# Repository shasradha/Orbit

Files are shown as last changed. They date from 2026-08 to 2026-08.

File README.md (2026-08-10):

<div align="center">

# Orbit ⌚⚡

**A wearable WiFi security-testing platform, disguised as a wristwatch.**

Custom ESP8266 hardware inside a repurposed SKMEI watch case, running a modified build of Spacehuhn's ESP8266 Deauther. This repository is the complete build: KiCad schematics, bill of materials, 3D enclosure model, and adapted firmware.







[Overview](#overview) • [Hardware](#hardware) • [Firmware](#firmware) • [3D Model](#3d-model) • [Gallery](#gallery) • [Legal](#legal--ethical-use)

</div>

---

## Overview

Orbit turns a raw ESP-12E/F module into a wrist-worn WiFi security testing tool. It presents a small on-device menu — **Scan**, **Select**, **Attack**, **Packet Monitor**, **Clock** — navigated with three tactile buttons, and reports live channel activity on a 128×64 OLED.

| | |
|---|---|
| **Form factor** | Modified SKMEI digital watch case |
| **MCU** | ESP-12E / ESP-12F (ESP8266) |
| **Display** | 0.96" I2C OLED (SSD1306, 128×64)
| **Input** | 3× tactile buttons (Up / Down / OK) + Flash + Reset |
| **Status LED** | WS2812B addressable RGB |
| **Power** | 3.7V single-cell LiPo |
| **Firmware base** | [Spacehuhn ESP8266 Deauther](https://github.com/SpacehuhnTech/esp8266_deauther) (MIT), re-pinned and rebranded |

This repo covers both halves of the build:

- **`hardware/`** — KiCad schematics for the main board and a standalone FT232RL-based flasher board, with PDF/SVG exports so nothing requires KiCad installed to review.
- **`firmware/`** — the Deauther source, adapted to Orbit's exact GPIO map, plus a prebuilt binary in [Releases](../../releases).

> [!WARNING]
> Orbit can interfere with wireless communications (deauthentication, scanning, packet capture). Use it only on networks you own or are explicitly authorized in writing to test. Unauthorized use may violate wireless regulations (e.g. FCC Part 15 in the US) and computer-misuse laws in most jurisdictions. See [Legal & Ethical Use](#legal--ethical-use).

---

## Hardware

### Specifications

| Component | Spec |
|---|---|
| MCU | ESP-12E / ESP-12F (ESP8266) |
| Display | 0.96" I2C OLED (SSD1306, 128×64) |
| Buttons | 3× tactile (Up / Down / OK) + Flash + Reset |
| LED | WS2812B RGB, single pixel |
| Power | 3.7V single-cell LiPo, no regulator |
| Case | Modified SKMEI digital watch |

### Pinout

| Function | GPIO |
|---|---|
| Button UP | 14 |
| Button DOWN | 12 |
| Button OK | 13 |
| OLED SCL | 5 |
| OLED SDA | 4 |
| WS2812 DIN | 2 |
| Flash button | 0 |
| Reset | RST |

### Bill of Materials

| Qty | Part |
|---|---|
| 1× | ESP-12E/F module |
| 1× | 0.96" I2C OLED (SSD1306, 128×64) |
| 1× | WS2812B RGB LED breakout |
| 5× | Tactile push buttons |
| 5× | 10kΩ resistors (boot config + pull-down) |
| 1× | 3.7V LiPo battery (400 mAh+) |
| 1× | SPST slide switch |
| 1× | FT232RL USB-TTL module (flasher board only) |
| — | SKMEI digital watch case (donor) |

### Schematics

Full KiCad source lives in [`hardware/`](./hardware). PDF and SVG exports are included alongside the `.kicad_sch` files for quick review without installing KiCad.

| Board | Purpose | Files |
|---|---|---|
| **Main board** | Orbit watch — ESP-12E, OLED, buttons, WS2812, battery | `hardware/orbit-main-circuit.kicad_sch` · [PDF](./hardware/orbit-main-circuit.pdf) · [SVG](./hardware/orbit-main-circuit.svg) |
| **Flasher board** | FT232RL USB-TTL programmer for initial flashing | `hardware/orbit-flash-circuit.kicad_sch` · [PDF](./hardware/orbit-flash-circuit.pdf) · [SVG](./hardware/orbit-flash-circuit.svg) |

> **Note:** on the flasher board, UART is crossed as expected for serial programming — FT232 TXD → ESP RXD0/GPIO3, FT232 RXD → ESP TXD0/GPIO1.

---

## Firmware

Orbit's firmware is a modified build of [spacehuhn's ESP8266 Deauther](https://github.com/SpacehuhnTech/esp8266_deauther) (MIT License), re-pinned to Orbit's GPIO map with a rebranded boot screen. See [`NOTICE.md`](./NOTICE.md) for the exact scope of modifications and attribution.

### Get the prebuilt binary

Grab `Orbit-firmware-v1.0.bin` from [**Releases**](../../releases/latest) and flash directly — no build environment required.

### Build from source

```bash
git clone https://github.com/shasradha/Orbit.git
cd Orbit/firmware/Orbit-Firmware-Source/orbit_deauther
```

1. Open `orbit_deauther.ino` in **Arduino IDE 2**.
2. Install the ESP8266 board package: *Tools → Board → Boards Manager → search "esp8266"*.
3. Select **Generic ESP8266 Module** as the target board.
4. Compile.

### Flashing

Use the included [flasher circuit](./hardware/orbit-flash-circuit.pdf) (FT232RL-based) or any USB-TTL adapter:

```bash
esptool.py -p <PORT> -b 115200 write_flash 0 Orbit-firmware-v1.0.bin
```

### Status

Compiles cleanly against Orbit's custom pin configuration. **Not yet flash-tested on physical hardware after this specific pin remap** — testing reports and issues are welcome. The underlying hardware, OLED wiring, and button layout have been verified working on this exact board (see [Gallery](#gallery)).

---

## 3D Model

A 3D reconstruction of the Orbit enclosure, built from real device photos and refined in Blender, is available for interactive preview:

**→ [Orbit — 3D Model (Tripo3D)](https://studio.tripo3d.ai/3d-model/440f1f53-c45f-4885-87b7-a15c8f742168?invite_code=AO12LG)**

This is an AI-assisted reconstruction for visual reference only — it is **not dimensionally exact**. The Blender source file is in [`hardware/3d/`](./hardware/3d) for anyone who wants to inspect or rebuild it.

<div align="center">
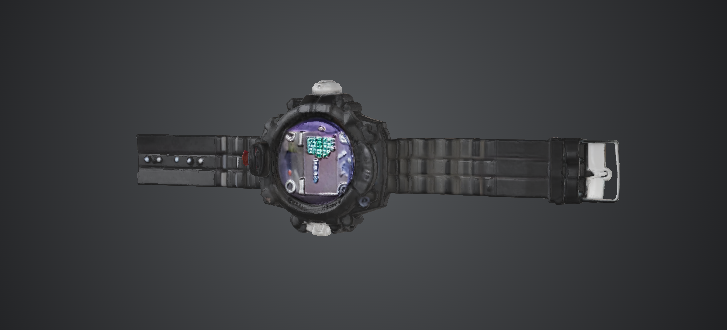
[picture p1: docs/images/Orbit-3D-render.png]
Orbit 3D render

</div>

https://github.com/user-attachments/assets/320ed174-5218-427d-8676-f516c165184d

---

## Gallery

<table>
<tr>
<td width="50%">
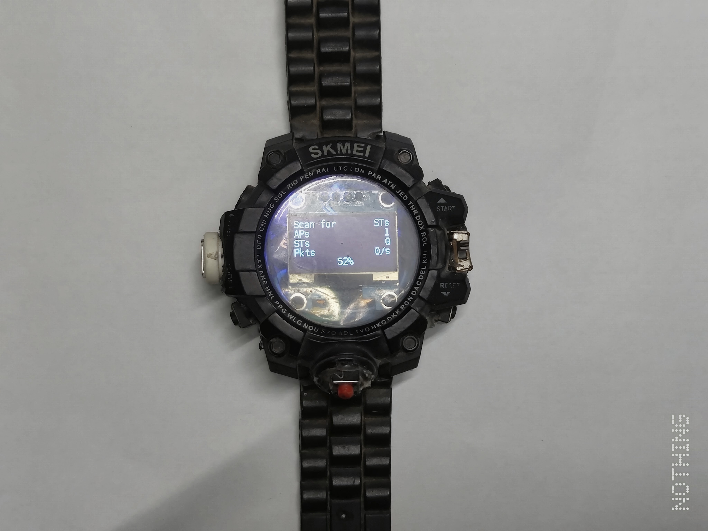
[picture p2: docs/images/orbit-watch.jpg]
Orbit assembled and worn

<p align="center"><em>Orbit, assembled and running</em></p>
</td>
<td width="50%">
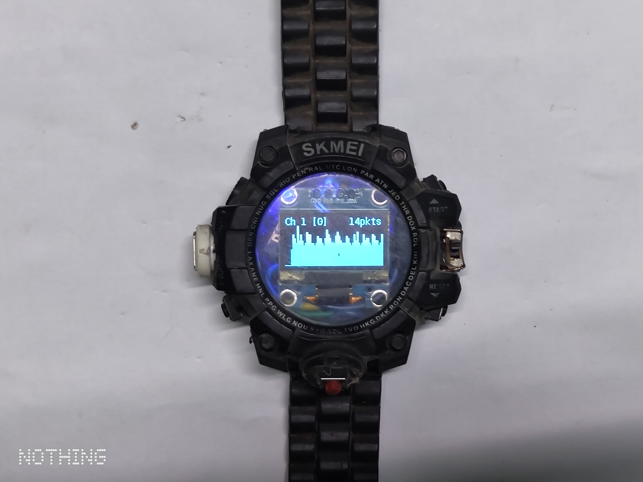
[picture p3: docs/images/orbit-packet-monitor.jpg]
Orbit packet monitor screen

<p align="center"><em>Live WiFi channel activity monitor</em></p>
</td>
</tr>
</table>

<div align="center">
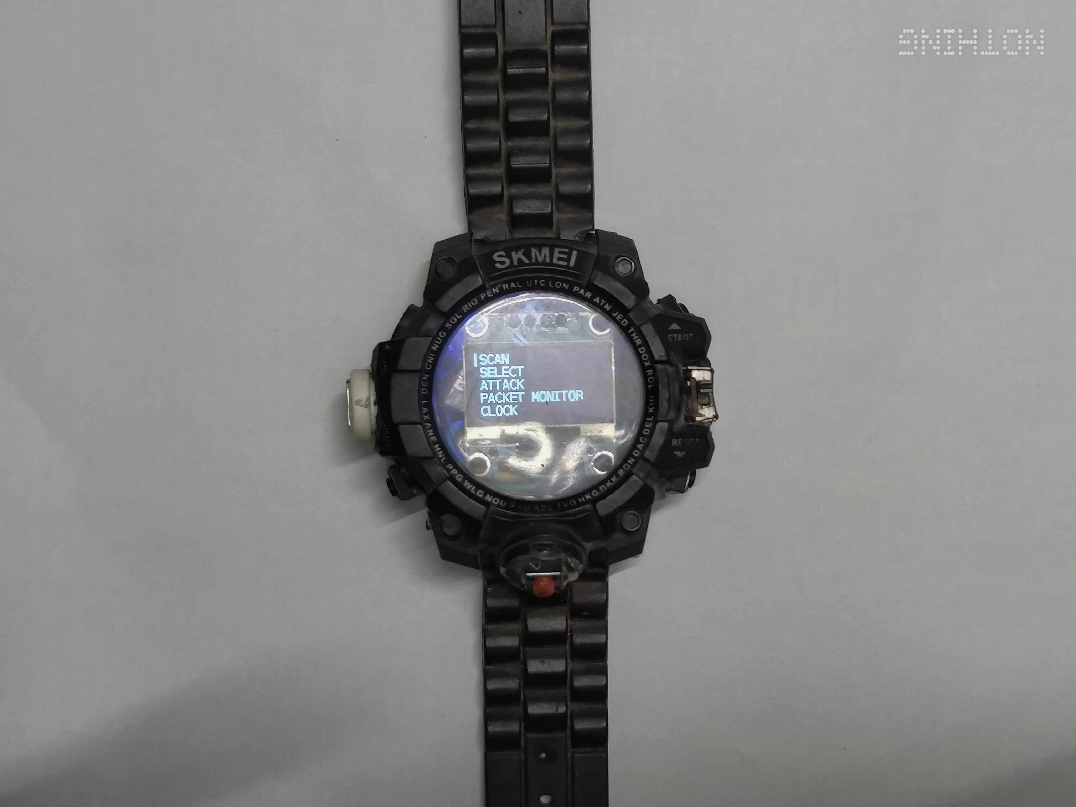
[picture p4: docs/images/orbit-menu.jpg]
Orbit main menu — Scan, Select, Attack, Packet Monitor, Clock

<p><em>On-device menu: Scan · Select · Attack · Packet Monitor · Clock</em></p>
</div>

---

## Roadmap

- [ ] Flash-test v1.0 firmware on the re-pinned hardware and confirm all menu functions
- [ ] Publish assembly / disassembly guide for the SKMEI case mod
- [ ] Add case STL/3MF export for 3D-printed enclosures
- [ ] Battery life benchmarking

---

## Contributing

Issues and pull requests are welcome — particularly flash-test reports, hardware revisions, and firmware fixes. For anything touching the deauther core itself, consider contributing upstream to [SpacehuhnTech/esp8266_deauther](https://github.com/SpacehuhnTech/esp8266_deauther) as well.

---

## Legal & Ethical Use

This project is published for **authorized security research and education only**.

- Only test networks you own, or have explicit written authorization to test.
- Deauthentication and RF interference are regulated in most jurisdictions (e.g. FCC Part 15 in the US) — unauthorized use may violate wireless and computer-misuse law.
- Per the upstream license: **do not redistribute, advertise, or sell this software (or Orbit) as a "jammer."**
- The author is not responsible for misuse of this tool.

---

## Credits

- **[Spacehuhn Technologies](https://github.com/SpacehuhnTech)** — original ESP8266 Deauther firmware (MIT License)
- **[Shasradha Karmakar](https://github.com/shasradha)** — hardware design, KiCad schematics, GPIO remap, and firmware adaptation for the Orbit platform

---

## License

MIT — see [`LICENSE`](./LICENSE) for the original firmware license and [`NOTICE.md`](./NOTICE.md) for Orbit-specific hardware and firmware modifications. Hardware design (KiCad files, BOM, 3D model) is also released under MIT.

</div>

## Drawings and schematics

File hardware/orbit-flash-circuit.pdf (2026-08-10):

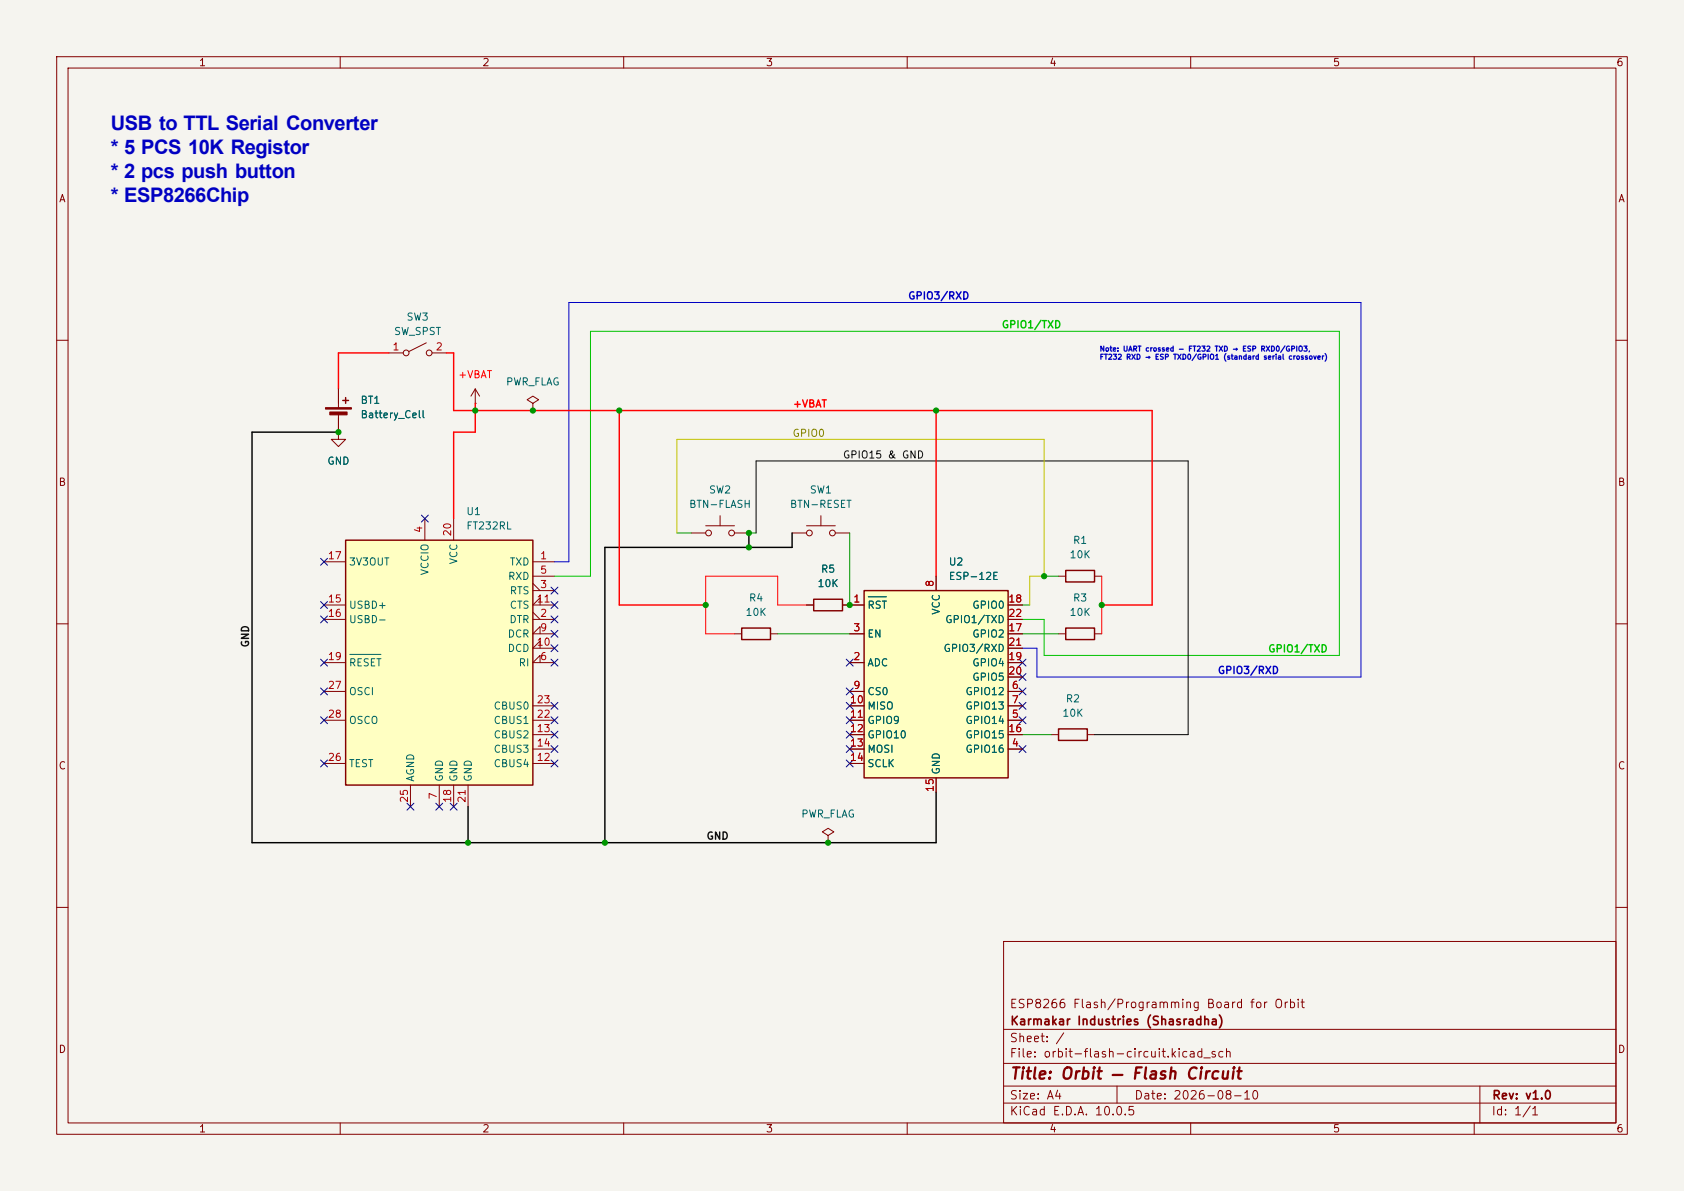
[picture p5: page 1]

GPIO15 & GND +VBAT USB to TTL Serial Converter
* 5 PCS 10K Registor
* 2 pcs push button
* ESP8266Chip

Note: UART crossed - FT232 TXD → ESP RXD0/GPIO3, FT232 RXD → ESP TXD0/GPIO1 (standard serial crossover) R5

7 DCR 9 DCD 10 CTS 11 CBUS4 12 CBUS2 13 CBUS3 14 USBD+ 15 USBD- 16

ESP8266 Flash/Programming Board for Orbit
Karmakar Industries (Shasradha)
Sheet: /
File: orbit-flash-circuit.kicad_sch
Title: Orbit — Flash Circuit

Size: A4 | Rev: v1.0
KiCad E.D.A. 10.0.5 | Id: 1/1

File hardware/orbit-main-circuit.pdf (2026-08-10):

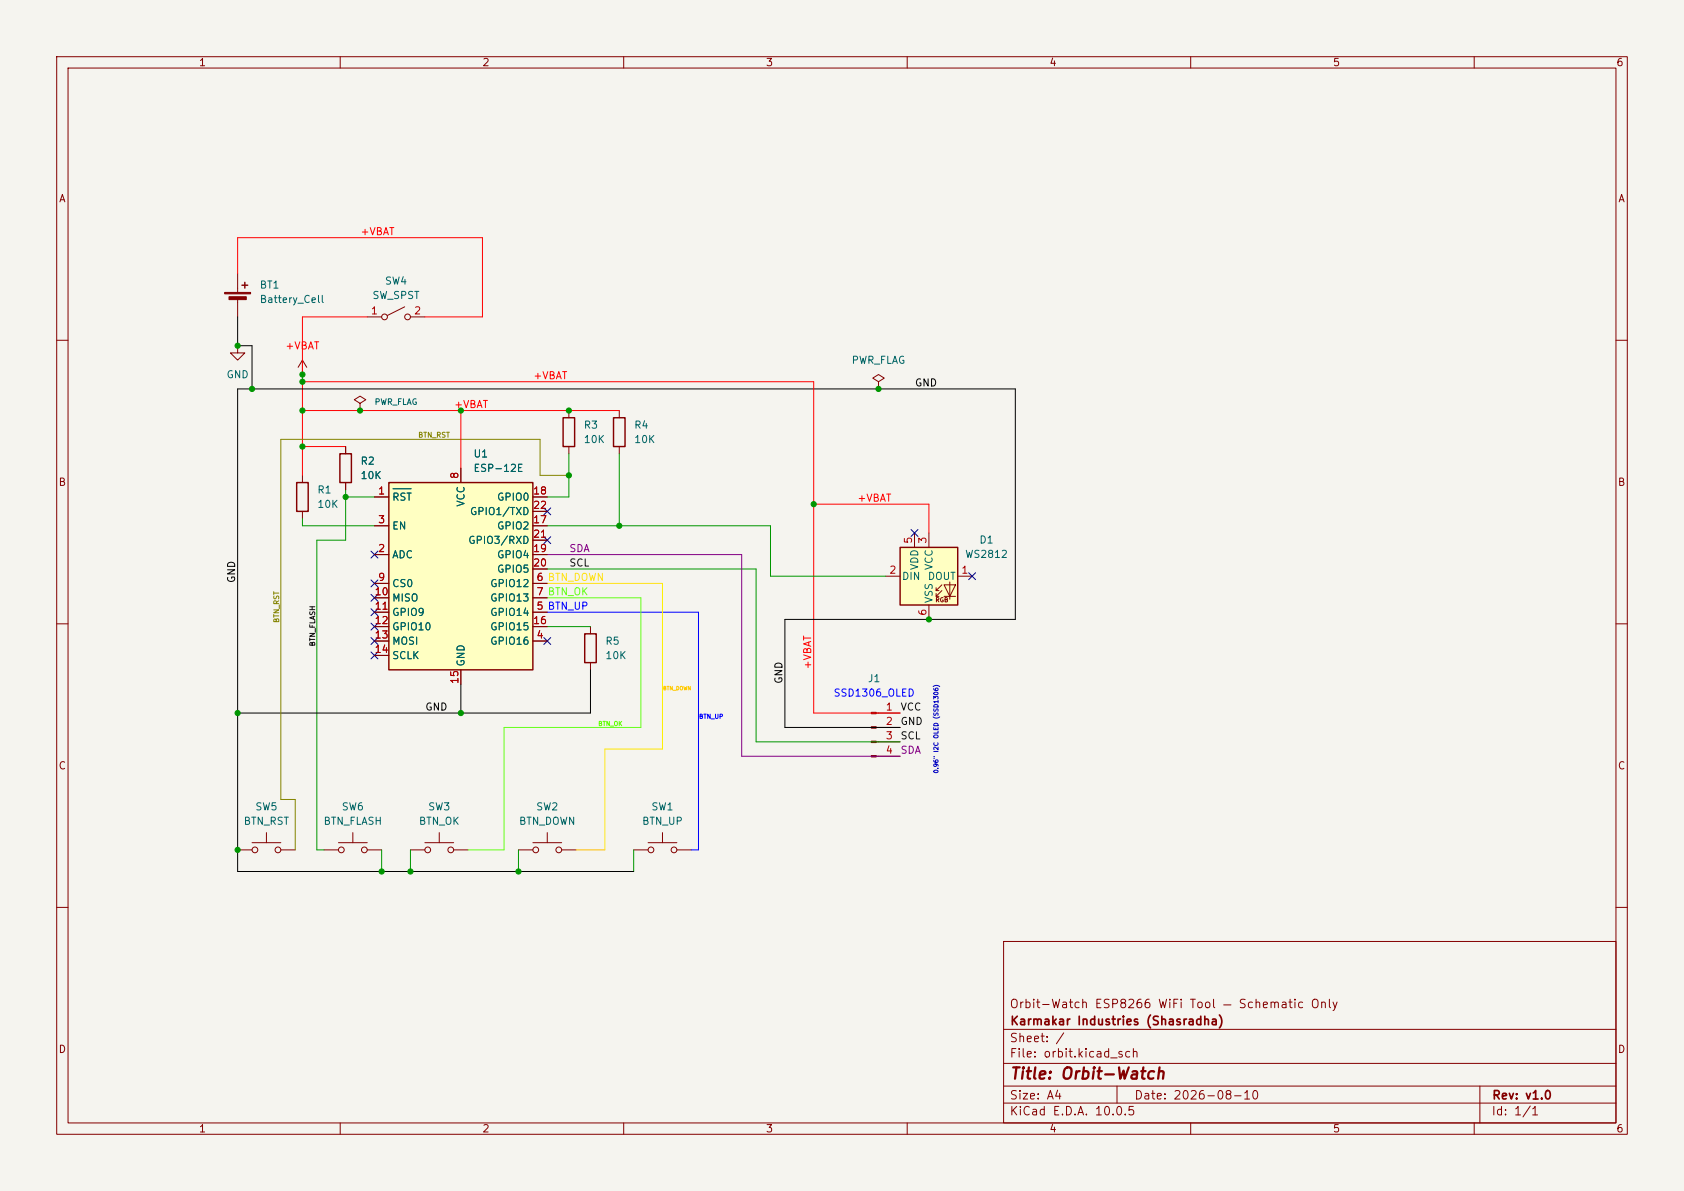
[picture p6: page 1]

Size: A4 | Rev: v1.0
KiCad E.D.A. 10.0.5 | Id: 1/1

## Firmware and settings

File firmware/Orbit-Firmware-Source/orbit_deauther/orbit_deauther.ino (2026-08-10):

/* This software is licensed under the MIT License: https://github.com/spacehuhntech/esp8266_deauther */

/* Modified for the Orbit hardware platform
   https://github.com/shasradha/Orbit
   Original firmware (c) spacehuhn, used under MIT License */

extern "C" {
    // Please follow this tutorial:
    // https://github.com/spacehuhn/esp8266_deauther/wiki/Installation#compiling-using-arduino-ide
    // And be sure to have the right board selected
  #include "user_interface.h"
}

#include "EEPROMHelper.h"

#include "src/ArduinoJson-v5.13.5/ArduinoJson.h"
#if ARDUINOJSON_VERSION_MAJOR != 5
// The software was build using ArduinoJson v5.x
// version 6 is still in beta at the time of writing
// go to tools -> manage libraries, search for ArduinoJSON and install version 5
#error Please upgrade/downgrade ArduinoJSON library to version 5!
#endif // if ARDUINOJSON_VERSION_MAJOR != 5

#include "oui.h"
#include "language.h"
#include "functions.h"
#include "settings.h"
#include "Names.h"
#include "SSIDs.h"
#include "Scan.h"
#include "Attack.h"
#include "CLI.h"
#include "DisplayUI.h"
#include "A_config.h"

#include "led.h"

// Run-Time Variables //
Names names;
SSIDs ssids;
Accesspoints accesspoints;
Stations     stations;
Scan   scan;
Attack attack;
CLI    cli;
DisplayUI displayUI;

simplebutton::Button* resetButton;

#include "wifi.h"

uint32_t autosaveTime = 0;
uint32_t currentTime  = 0;

bool booted = false;

void setup() {
    // for random generator
    randomSeed(os_random());

    // start serial
    Serial.begin(115200);
    Serial.println();

    // start SPIFFS
    prnt(SETUP_MOUNT_SPIFFS);
    // bool spiffsError = !LittleFS.begin();
    LittleFS.begin();
    prntln(/*spiffsError ? SETUP_ERROR : */ SETUP_OK);

    // Start EEPROM
    EEPROMHelper::begin(EEPROM_SIZE);

#ifdef FORMAT_SPIFFS
    prnt(SETUP_FORMAT_SPIFFS);
    LittleFS.format();
    prntln(SETUP_OK);
#endif // ifdef FORMAT_SPIFFS

#ifdef FORMAT_EEPROM
    prnt(SETUP_FORMAT_EEPROM);
    EEPROMHelper::format(EEPROM_SIZE);
    prntln(SETUP_OK);
#endif // ifdef FORMAT_EEPROM

    // Format SPIFFS when in boot-loop
    if (/*spiffsError || */ !EEPROMHelper::checkBootNum(BOOT_COUNTER_ADDR)) {
        prnt(SETUP_FORMAT_SPIFFS);
        LittleFS.format();
        prntln(SETUP_OK);

        prnt(SETUP_FORMAT_EEPROM);
        EEPROMHelper::format(EEPROM_SIZE);
        prntln(SETUP_OK);

        EEPROMHelper::resetBootNum(BOOT_COUNTER_ADDR);
    }

    // get time
    currentTime = millis();

    // load settings
    #ifndef RESET_SETTINGS
    settings::load();
    #else // ifndef RESET_SETTINGS
    settings::reset();
    settings::save();
    #endif // ifndef RESET_SETTINGS

    wifi::begin();
    wifi_set_promiscuous_rx_cb([](uint8_t* buf, uint16_t len) {
        scan.sniffer(buf, len);
    });

    // start display
    if (settings::getDisplaySettings().enabled) {
        displayUI.setup();
        displayUI.mode = DISPLAY_MODE::INTRO;
    }

    // load everything else
    names.load();
    ssids.load();
    cli.load();

    // create scan.json
    scan.setup();

    // dis/enable serial command interface
    if (settings::getCLISettings().enabled) {
        cli.enable();
    } else {
        prntln(SETUP_SERIAL_WARNING);
        Serial.flush();
        Serial.end();
    }

    // start access point/web interface
    if (settings::getWebSettings().enabled) wifi::startAP();

    // STARTED
    prntln(SETUP_STARTED);

    // version
    prntln(DEAUTHER_VERSION);

    // setup LED
    led::setup();

    // setup reset button
    resetButton = new ButtonPullup(RESET_BUTTON);
}

void loop() {
    currentTime = millis();

    led::update();   // update LED color
    wifi::update();  // manage access point
    attack.update(); // run attacks
    displayUI.update();
    cli.update();    // read and run serial input
    scan.update();   // run scan
    ssids.update();  // run random mode, if enabled

    // auto-save
    if (settings::getAutosaveSettings().enabled
        && (currentTime - autosaveTime > settings::getAutosaveSettings().time)) {
        autosaveTime = currentTime;
        names.save(false);
        ssids.save(false);
        settings::save(false);
    }

    if (!booted) {
        booted = true;
        EEPROMHelper::resetBootNum(BOOT_COUNTER_ADDR);
#ifdef HIGHLIGHT_LED
        displayUI.setupLED();
#endif // ifdef HIGHLIGHT_LED
    }

    resetButton->update();
    if (resetButton->holding(5000)) {
        led::setMode(LED_MODE::SCAN);
        DISPLAY_MODE _mode = displayUI.mode;
        displayUI.mode = DISPLAY_MODE::RESETTING;
        displayUI.update(true);

        settings::reset();
        settings::save(true);

        delay(2000);

        led::setMode(LED_MODE::IDLE);
        displayUI.mode = _mode;
    }
}

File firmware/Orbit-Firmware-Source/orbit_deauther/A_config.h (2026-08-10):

/* This software is licensed under the MIT License: https://github.com/spacehuhntech/esp8266_deauther */

/* Modified for the Orbit hardware platform
   https://github.com/shasradha/Orbit
   Original firmware (c) spacehuhn, used under MIT License */

#pragma once

#define ENABLE_DEBUG
#define DEBUG_PORT Serial
#define DEBUG_BAUD 115200

#define ORBIT
//#define DEFAULT_ESP8266

// #define NODEMCU
// #define WEMOS_D1_MINI
// #define HACKHELD_VEGA
// #define DISPLAY_EXAMPLE_I2C
// #define DISPLAY_EXAMPLE_SPI

// #define MALTRONICS
// #define DSTIKE_DEAUTHER_V1
// #define DSTIKE_DEAUTHER_V2
// #define DSTIKE_DEAUTHER_V3
// #define DSTIKE_DEAUTHER_V3_5
// #define DSTIKE_D_DUINO_B_V5_LED_RING
// #define DSTIKE_DEAUTHER_BOY
// #define DSTIKE_NODEMCU_07
// #define DSTIKE_NODEMCU_07_V2
// #define DSTIKE_DEAUTHER_OLED
// #define DSTIKE_DEAUTHER_OLED_V1_5_S
// #define DSTIKE_DEAUTHER_OLED_V1_5
// #define DSTIKE_DEAUTHER_OLED_V2
// #define DSTIKE_DEAUTHER_OLED_V2_5
// #define DSTIKE_DEAUTHER_OLED_V3
// #define DSTIKE_DEAUTHER_OLED_V3_5
// #define DSTIKE_DEAUTHER_OLED_V4
// #define DSTIKE_DEAUTHER_OLED_V5
// #define DSTIKE_DEAUTHER_OLED_V6
// #define DSTIKE_DEAUTHER_MOSTER
// #define DSTIKE_DEAUTHER_MOSTER_V2
// #define DSTIKE_DEAUTHER_MOSTER_V3
// #define DSTIKE_DEAUTHER_MOSTER_V4
// #define DSTIKE_DEAUTHER_MOSTER_V5
// #define DSTIKE_USB_DEAUTHER
// #define DSTIKE_USB_DEAUTHER_V2
// #define DSTIKE_DEAUTHER_WATCH
// #define DSTIKE_DEAUTHER_WATCH_V2
// #define DSTIKE_DEAUTHER_MINI
// #define DSTIKE_DEAUTHER_MINI_EVO

// #define LYASI_7W_E27_LAMP
// #define AVATAR_5W_E14_LAMP

// Forces formatting of SPIFFS and EEPROM ot startup
// #define FORMAT_SPIFFS
// #define FORMAT_EEPROM

// Forces a reset of all settings at startup
// #define RESET_SETTINGS

// ========== CONFIGS ========== //

// https://github.com/spacehuhntech/hackheld
#if defined(HACKHELD_VEGA)
// ===== LED ===== //
  #define USE_LED true
  #define LED_NEOPIXEL

  #define LED_NEOPIXEL_GRB
// #define LED_NEOPIXEL_RGB

  #define LED_MODE_BRIGHTNESS 10

  #define LED_NUM 1
  #define LED_NEOPIXEL_PIN 15 // D8

// ===== DISPLAY ===== //
  #define USE_DISPLAY true
  #define FLIP_DIPLAY true

  #define SH1106_I2C

  #define I2C_ADDR 0x3C
  #define I2C_SDA 4      // D2
  #define I2C_SCL 5      // D1

// ===== BUTTONS ===== //
  #define BUTTON_UP 14   // D5
  #define BUTTON_DOWN 12 // D6
  #define BUTTON_A 2     // D4
  #define BUTTON_B 0     // D3

// https://github.com/SpacehuhnTech/esp8266_deauther/wiki/Setup-Display-&-Buttons#example-setup-with-i2c-oled
#elif defined(DISPLAY_EXAMPLE_I2C)

// ===== DISPLAY ===== //
  #define SH1106_I2C
// #define SSD1306_I2C

  #define I2C_ADDR 0x3C
  #define I2C_SDA 5
  #define I2C_SCL 4

// #define FLIP_DIPLAY true

// ===== BUTTONS ===== //
  #define BUTTON_UP 14
  #define BUTTON_DOWN 12
  #define BUTTON_A 13

// ===== LED ===== //
  #define LED_NEOPIXEL_GRB
// #define LED_NEOPIXEL_RGB

  #define LED_NUM 1
  #define LED_NEOPIXEL_PIN 9
  #define LED_MODE_BRIGHTNESS 10


// https://github.com/SpacehuhnTech/esp8266_deauther/wiki/Setup-Display-&-Buttons#example-setup-with-spi-oled
#elif defined(DISPLAY_EXAMPLE_SPI)

  #define SH1106_SPI
// #define SSD1306_SPI

  #define SPI_RES 5
  #define SPI_DC 4
  #define SPI_CS 15

// #define FLIP_DIPLAY true

// ===== BUTTONS ===== //
  #define BUTTON_UP 0
  #define BUTTON_DOWN 12
  #define BUTTON_A 2

// ===== LED ===== //
  #define LED_NEOPIXEL_GRB
// #define LED_NEOPIXEL_RGB

  #define LED_NUM 1
  #define LED_NEOPIXEL_PIN 9
  #define LED_MODE_BRIGHTNESS 10

#elif defined(MALTRONICS)

// ===== Reset ====== //
  #define RESET_BUTTON 5

// ===== LED ===== //
  #define LED_DOTSTAR
  #define LED_NUM 1
  #define LED_DOTSTAR_CLK 12
  #define LED_DOTSTAR_DATA 13
  #define LED_MODE_BRIGHTNESS 255

// ===== Web ===== //
#define WEB_IP_ADDR (192, 168, 4, 2)
#define WEB_URL "deauther.tools"

#elif defined(DSTIKE_D_DUINO_B_V5_LED_RING)

// ===== LED ===== //
  #define LED_NEOPIXEL_GRB
  #define LED_NUM 12
  #define LED_NEOPIXEL_PIN 15

// ===== DISPLAY ===== //
  #define SH1106_I2C
  #define FLIP_DIPLAY true
  #define DISPLAY_TEXT "Hardware by DSTIKE"

// ===== BUTTONS ===== //
  #define BUTTON_UP 12
  #define BUTTON_DOWN 13
  #define BUTTON_A 14

#elif defined(DSTIKE_DEAUTHER_BOY)

// ===== LED ===== //
  #define LED_NEOPIXEL_GRB
  #define LED_NUM 1
  #define LED_NEOPIXEL_PIN 15

// ===== DISPLAY ===== //
  #define SH1106_I2C
  #define FLIP_DIPLAY true
  #define DISPLAY_TEXT "Hardware by DSTIKE"

// ===== BUTTONS ===== //
  #define BUTTON_UP 10
  #define BUTTON_DOWN 9
  #define BUTTON_A 14
  #define BUTTON_B 12

#elif defined(DSTIKE_DEAUTHER_V3_5) || defined(DSTIKE_NODEMCU_07_V2)

// ===== LED ===== //
  #define LED_NEOPIXEL_GRB
  #define LED_NUM 1
  #define LED_NEOPIXEL_PIN 15

#elif defined(DSTIKE_DEAUTHER_OLED_V1_5_S)

// ===== LED ===== //
  #define LED_NEOPIXEL_GRB
  #define LED_NUM 1
  #define LED_NEOPIXEL_PIN 15
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
